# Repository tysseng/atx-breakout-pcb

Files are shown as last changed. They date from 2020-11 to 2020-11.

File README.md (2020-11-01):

# atx-breakout-pcb

## Overview:
24p atx has:
- 4 x 3.3v
- 4 x 5v
- 2 x 12V1
- 1 x -12V
- 1 x -5V
- 8 x GND/COM
- 1 x 5V standby (always on)
- 1 x PS on
- 1 x PWR OK

Each channel: MAX 6A

## Initial spec from Stig-Rune:
- 24p ATX molex IN
- ATX motherboard power connector (Molex Mini-fit Jr. 39-28-1203,[7] former 5566-20A or 39-28-1243,[8] former 5566-24A)

### Eksponere pin som aktiverer PSU
- Vil du også ha en knapp på kortet? 
  <- nei, men om denne eksponeres som en 2p header så kan jeg putte en jumper der initielt, eller lodde på en av de kontaktene vi har på skuret
  -- Tenker jeg lager plass nok til en knapp likevel jeg, hvis det er plass :-D

### Eksponere pin som gir 5v når PSU er stabil
- Hva slags connector <- tenkte vanlig 2p header, så kan jeg enten bruke pins eller en 2p kontakt fra skuret
- Auto-start av Mosfets via jumper, see channel.

### Eksponere 5v standby
- Hva slags connector? <- igjen tenkte jeg å bruke vanlig pin-headers

### Eksponere 4x standard fan headere (12v + pwm + rpm), hvor pwm og rpm pins er eksponert et sted slik at jeg kan styre pwm og lese rpm med rpi eller arduino
- 12V fra en av kanalene, 8 I/O-pinner?  :+1:
- Bruke 10p IDC connector med GND og 5V i tillegg? <- høres ikke dumt ut :)

### Eksponere 4x USB-kontakter, 
- gjerne med 5A sikringer og noe som sørger for god strømlevering. 
- Kanskje også kontrollere disse via mosfets og eksponere pins for å styre dem, på en måte som lar meg sette på jumper for å enable kontaktene permanent.

### Eksponere 12v og 5v som hull til XT30 og pin-headere
- Max amp for pin header - flere pins pr. connector for samme volt? <- XT30 takler opp til 30A, var denne jeg tenkte for 12v. tenkte pin headere for 5v som mest sannsynlig blir typ arduinoer osv, så lite strøm.
- Både V+ og GND

## Løsningsforslag

### Channels:
- Mosfet control
- Cooling ribs
- control pin exposed for RPI/Ard.
- Jumper or DIP-switch to override control pin
- Automatic power on after PWR OK goes hi - connected through jumper or DIP-SWITCH 
- Indicator LED? After MOSFET
- 5A Fuse
- Filter and buffer caps
- pins and XT30 connector per channel, top mounted
- USB for 5V channel, edge mounted (?)
- Screw terminals for 12V (and others?)

- Shared 10p or 16p IDC connector depending on how many channels we want to expose (12 available)
	- OR use SPI with port expander chip to reduce the number of wires needed.
- 16p has room for 12 channels, gnd, 5v always on, ps on and pwr ok.
- May combine with 8-10p for fan control.
	- make pin-compatible with Raspberry? <- smart! jeg trenger ikke det tror jeg, men ser ikke noe grunn til å la vær fordet
	- May or may not use full 40p connector.

### Fan control
- 10p IDC for two pins/channel, GND, +5V
- Common 12v from the ATX PSU

## Research

ATX Pinouts:
- https://www.smpspowersupply.com/connectors-pinouts.html

Molex contact
- The P1 uses Molex Housing Mini-Fit Jr. P/N# 39-01-2240 style, motherboard header is Molex 44206-0007

Mosfet control
- Negative side: https://bildr.org/2012/03/rfp30n06le-arduino/
- Positive side, Vcc > 5v: https://www.gammon.com.au/motors

Other
- Minimum current requirement on 5V for startup? "From what i read an old powersupply which has more ampeeres on 
  the 5v side needs at least 1A of minimum current.... so i will prolly need 10ohm 10W dummy load"
- Expose as separate connector to connect power resistor if needed??

PCB track width
- Calculator: https://www.4pcb.com/trace-width-calculator.html
- 5A: 109 MIL w 1 oz copper, 55MIL w 2 oz ($20 extra at dirtypcbs)

USB
- Stacked connectors?
- All on the same side

FUSES
- miniature automotive fuses or resettable pcb-mounted fuses?
- https://www.edn.com/protecting-against-reverse-polarity-methods-examined-part-1/

Power on-led
Power good-led

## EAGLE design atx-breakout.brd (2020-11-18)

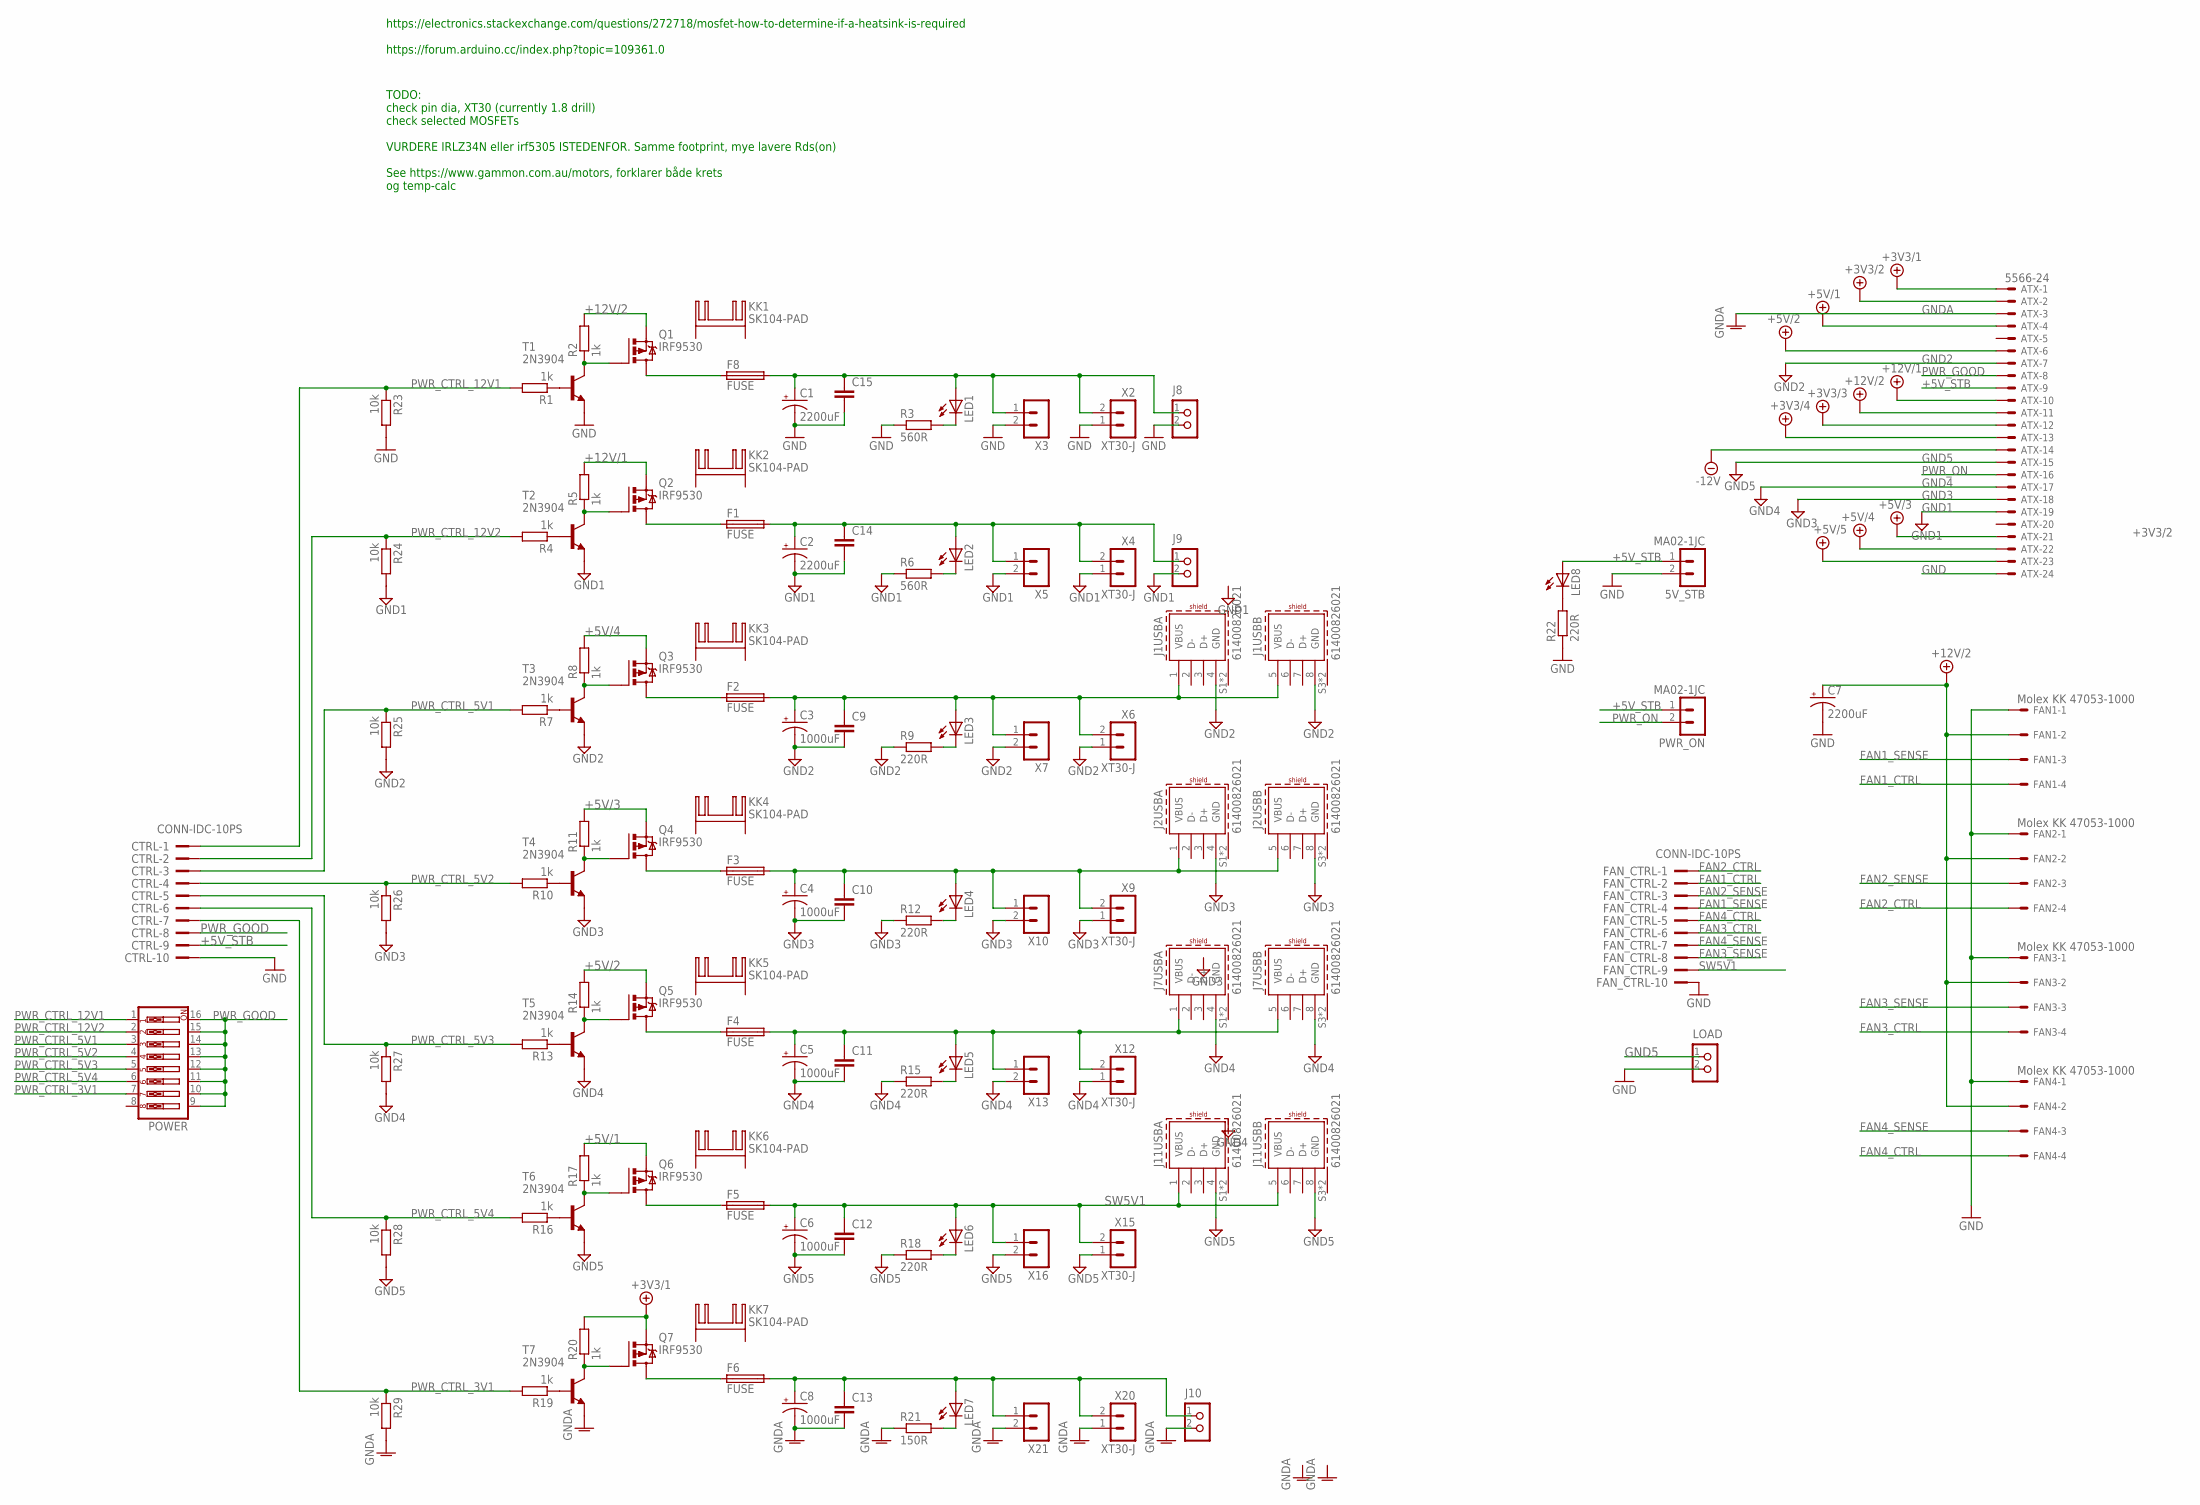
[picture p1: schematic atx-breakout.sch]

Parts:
5V_STB: MA02-1JC; MA02-1J
ATX: 5566-24
C1, C2, C7: 2200uF; E7,5-16
C3, C4, C5, C6, C8: 1000uF; E5-10,5
C9, C10, C11, C12, C13, C14, C15: C-EU050-030X075; C050-030X075
CTRL: CONN-IDC-10PS; CONN-IDC10P-S
F1, F2, F3, F4, F5, F6, F8: FUSE; FUSE_HOLDER_5X20MM
FAN1, FAN2, FAN3, FAN4: Molex KK 47053-1000; 6410-04
FAN_CTRL: CONN-IDC-10PS; CONN-IDC10P-S
J1, J2, J7, J11: 61400826021
J8, J9, J10: CON_TERMINAL_BLOCK_02-5MM; TERMINAL_BLOCK_2P_5
KK1, KK2, KK3, KK4, KK5, KK6, KK7: SK104-PAD
LED1, LED2, LED3, LED4, LED5, LED6, LED7, LED8: LED_J3MM; LED3MM
LOAD: CON_TERMINAL_BLOCK_02-5MM; TERMINAL_BLOCK_2P_5
POWER: SW_DIP-8; EDG-08
PWR_ON: MA02-1JC; MA02-1J
Q1, Q2, Q3, Q4, Q5, Q6, Q7: IRF9530; TO220BV
R1, R2, R4, R5, R7, R8, R10, R11, R13, R14, R16, R17, R19, R20: 1k; 0207/7
R3, R6: 560R; 0207/7
R9, R12, R15, R18, R22: 220R; 0207/7
R21: 150R; 0207/7
R23, R24, R25, R26, R27, R28, R29: 10k; 0207/7
T1, T2, T3, T4, T5, T6, T7: 2N3904; TO92
X2, X4, X6, X9, X12, X15, X20: XT30-J
X3, X5, X7, X10, X13, X16, X21: MA02-1JC; MA02-1J

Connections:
+3V3/1: ATX.1, Q7.S, R20.2
+3V3/2: ATX.2
+3V3/3: ATX.12
+3V3/4: ATX.13
+5V: ATX.23
+5V/1: ATX.4, Q6.S, R17.2
+5V/2: ATX.6, Q5.S, R14.2
+5V/3: ATX.21, Q4.S, R11.2
+5V/4: ATX.22, Q3.S, R8.2
+5V_STB: 5V_STB.1, ATX.9, CTRL.9, LED8.A, PWR_ON.1
+12V/1: ATX.10, Q2.S, R5.2
+12V/2: ATX.11, C7.+, FAN1.2, FAN2.2, FAN3.2, FAN4.2, Q1.S, R2.2
-12V: ATX.14
FAN1_CTRL: FAN1.4, FAN_CTRL.2
FAN1_SENSE: FAN1.3, FAN_CTRL.4
FAN2_CTRL: FAN2.4, FAN_CTRL.1
FAN2_SENSE: FAN2.3, FAN_CTRL.3
FAN3_CTRL: FAN3.4, FAN_CTRL.6
FAN3_SENSE: FAN3.3, FAN_CTRL.8
FAN4_CTRL: FAN4.4, FAN_CTRL.5
FAN4_SENSE: FAN4.3, FAN_CTRL.7
GND: 5V_STB.2, ATX.24, C1.-, C7.-, C15.2, CTRL.10, FAN1.1, FAN2.1, FAN3.1, FAN4.1, FAN_CTRL.10, J8.2, LOAD.2, R3.1, R22.1, R23.2, T1.3 (E), X2.1, X3.2
GND1: ATX.19, C2.-, C14.2, J9.2, R6.1, R24.2, T2.3 (E), X4.1, X5.2
GND2: ATX.7, C3.-, C9.2, J1.4 (GND), J1.8 (GND), R9.1, R25.2, T3.3 (E), X6.1, X7.2
GND3: ATX.18, C4.-, C10.2, J2.4 (GND), J2.8 (GND), R12.1, R26.2, T4.3 (E), X9.1, X10.2
GND4: ATX.17, C5.-, C11.2, J7.4 (GND), J7.8 (GND), R15.1, R27.2, T5.3 (E), X12.1, X13.2
GND5: ATX.15, C6.-, C12.2, J11.4 (GND), J11.8 (GND), LOAD.1, R18.1, R28.2, T6.3 (E), X15.1, X16.2
GNDA: ATX.3, C8.-, C13.2, J10.2, R21.1, R29.2, T7.3 (E), X20.1, X21.2
unnamed: R1.1, T1.2 (B)
unnamed: Q1.G, R2.1, T1.1 (C)
unnamed: LED8.K (C), R22.2
unnamed: C1.+, C15.1, F8.2, J8.1, LED1.A, X2.2, X3.1
unnamed: LED1.K (C), R3.2
unnamed: F8.1, Q1.D
unnamed: R4.1, T2.2 (B)
unnamed: Q2.G, R5.1, T2.1 (C)
unnamed: C2.+, C14.1, F1.2, J9.1, LED2.A, X4.2, X5.1
unnamed: LED2.K (C), R6.2
unnamed: F1.1, Q2.D
unnamed: R7.1, T3.2 (B)
unnamed: Q3.G, R8.1, T3.1 (C)
unnamed: C3.+, C9.1, F2.2, J1.1 (VBUS), J1.5 (VBUS), LED3.A, X6.2, X7.1
unnamed: LED3.K (C), R9.2
unnamed: F2.1, Q3.D
unnamed: R10.1, T4.2 (B)
unnamed: Q4.G, R11.1, T4.1 (C)
unnamed: C4.+, C10.1, F3.2, J2.1 (VBUS), J2.5 (VBUS), LED4.A, X9.2, X10.1
unnamed: LED4.K (C), R12.2
unnamed: F3.1, Q4.D
unnamed: R13.1, T5.2 (B)
unnamed: Q5.G, R14.1, T5.1 (C)
unnamed: C5.+, C11.1, F4.2, J7.1 (VBUS), J7.5 (VBUS), LED5.A, X12.2, X13.1
unnamed: LED5.K (C), R15.2
unnamed: F4.1, Q5.D
unnamed: R16.1, T6.2 (B)
unnamed: Q6.G, R17.1, T6.1 (C)
unnamed: LED6.K (C), R18.2
unnamed: F5.1, Q6.D
unnamed: R19.1, T7.2 (B)
unnamed: Q7.G, R20.1, T7.1 (C)
unnamed: C8.+, C13.1, F6.2, J10.1, LED7.A, X20.2, X21.1
unnamed: LED7.K (C), R21.2
unnamed: F6.1, Q7.D
PWR_CTRL_3V1: CTRL.7, POWER.7, R19.2, R29.1
PWR_CTRL_5V1: CTRL.3, POWER.3, R7.2, R25.1
PWR_CTRL_5V2: CTRL.4, POWER.4, R10.2, R26.1
PWR_CTRL_5V3: CTRL.5, POWER.5, R13.2, R27.1
PWR_CTRL_5V4: CTRL.6, POWER.6, R16.2, R28.1
PWR_CTRL_12V1: CTRL.1, POWER.1, R1.2, R23.1
PWR_CTRL_12V2: CTRL.2, POWER.2, R4.2, R24.1
PWR_GOOD: ATX.8, CTRL.8, POWER.9, POWER.10, POWER.11, POWER.12, POWER.13, POWER.14, POWER.15, POWER.16
PWR_ON: ATX.16, PWR_ON.2
SW5V1: C6.+, C12.1, F5.2, FAN_CTRL.9, J11.1 (VBUS), J11.5 (VBUS), LED6.A, X15.2, X16.1

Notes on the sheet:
TODO: check pin dia, XT30 (currently 1.8 drill) check selected MOSFETs VURDERE IRLZ34N eller irf5305 ISTEDENFOR. Samme footprint, mye lavere Rds(on) See https://www.gammon.com.au/motors, forklarer både krets og temp-calc
https://electronics.stackexchange.com/questions/272718/mosfet-how-to-determine-if-a-heatsink-is-required https://forum.arduino.cc/index.php?topic=109361.0

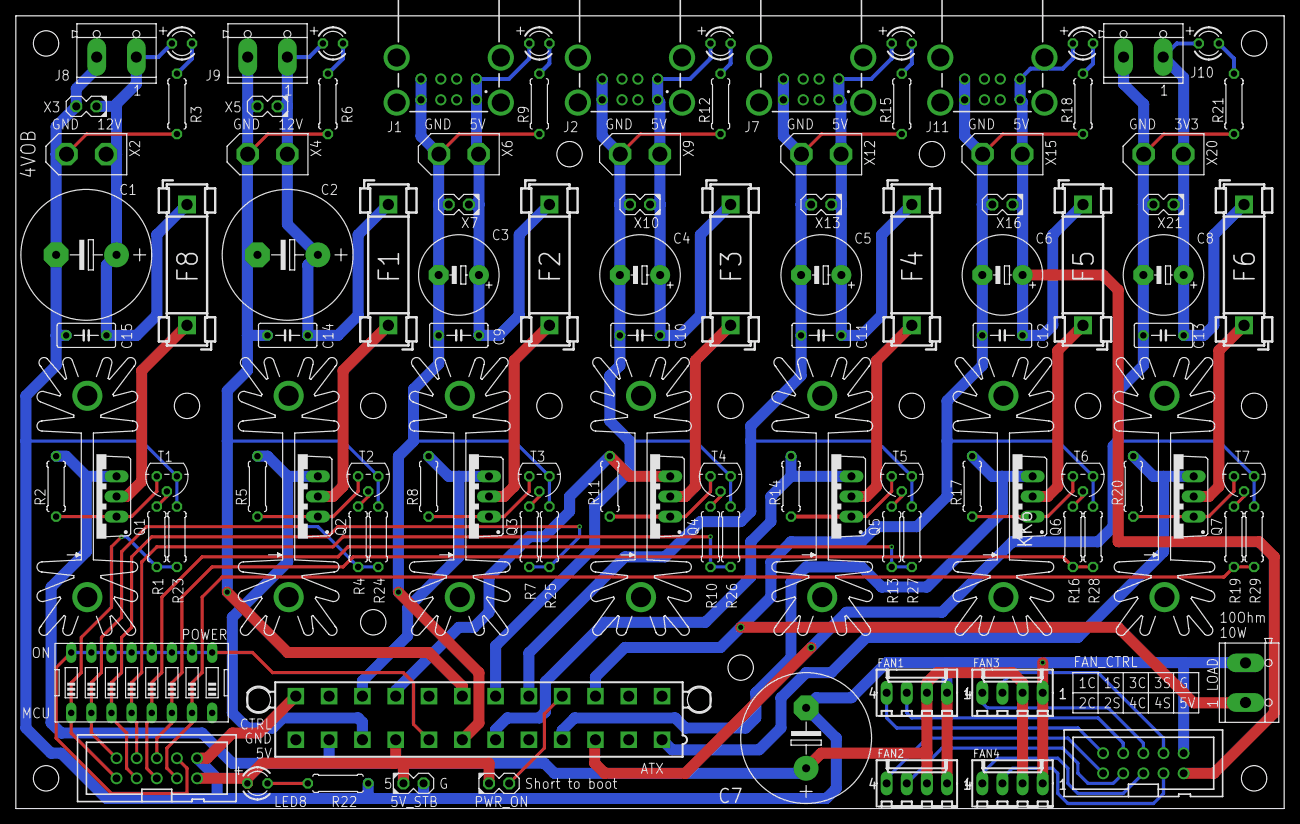
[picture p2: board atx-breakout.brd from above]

Board: 2 copper layers, 160.0 x 100.0 mm, 113 parts (1 on the bottom side), 68 nets.

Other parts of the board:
U$1: XONIK_LOGO_60

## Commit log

2020-10-31 Added ATX connector
    [atx-breakout.sch]
2020-11-01 Six channel version, initial layout
    [atx-breakout.brd, atx-breakout.sch]
2020-11-07 Added 3v3, control header, fan control headers, extra room for filter cap
    [atx-breakout.brd, atx-breakout.sch]
2020-11-07 More cleanup, made room for screws etc
    [atx-breakout.brd, atx-breakout.sch]
2020-11-07 Everything routed, but need to rething GND
    [atx-breakout.brd, atx-breakout.sch]
2020-11-08 Separate grounds for every channel
    [atx-breakout.brd, atx-breakout.sch]
2020-11-09 More mounting holes, screw terminal for 10Ohm load
    [atx-breakout.brd, atx-breakout.sch]
2020-11-18 Updated XT-30 footprint, updated pulldown resistor value
    [atx-breakout.brd, atx-breakout.sch]

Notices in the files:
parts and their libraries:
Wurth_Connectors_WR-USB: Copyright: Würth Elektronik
